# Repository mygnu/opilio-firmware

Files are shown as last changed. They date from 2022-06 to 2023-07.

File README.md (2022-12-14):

# opilio-firmware

Firmware for STM32F103C8 based custom board for PC water-cooling project.

Counterparts: 
- Linux TUI app can be found [here](https://github.com/mygnu/opilio)
- PCB Files [here](https://github.com/mygnu/opilio-pcb)

## Flashing an opilio board
- install rust from [rustup](https://rustup.rs)
- `cargo install probe-run cargo-flash flip-link`
- `git clone https://github.com/mygnu/opilio`
- `git clone https://github.com/mygnu/opilio-firmware`
- `cd opilio-firmware && cargo flash --chip STM32F103C8 --release`

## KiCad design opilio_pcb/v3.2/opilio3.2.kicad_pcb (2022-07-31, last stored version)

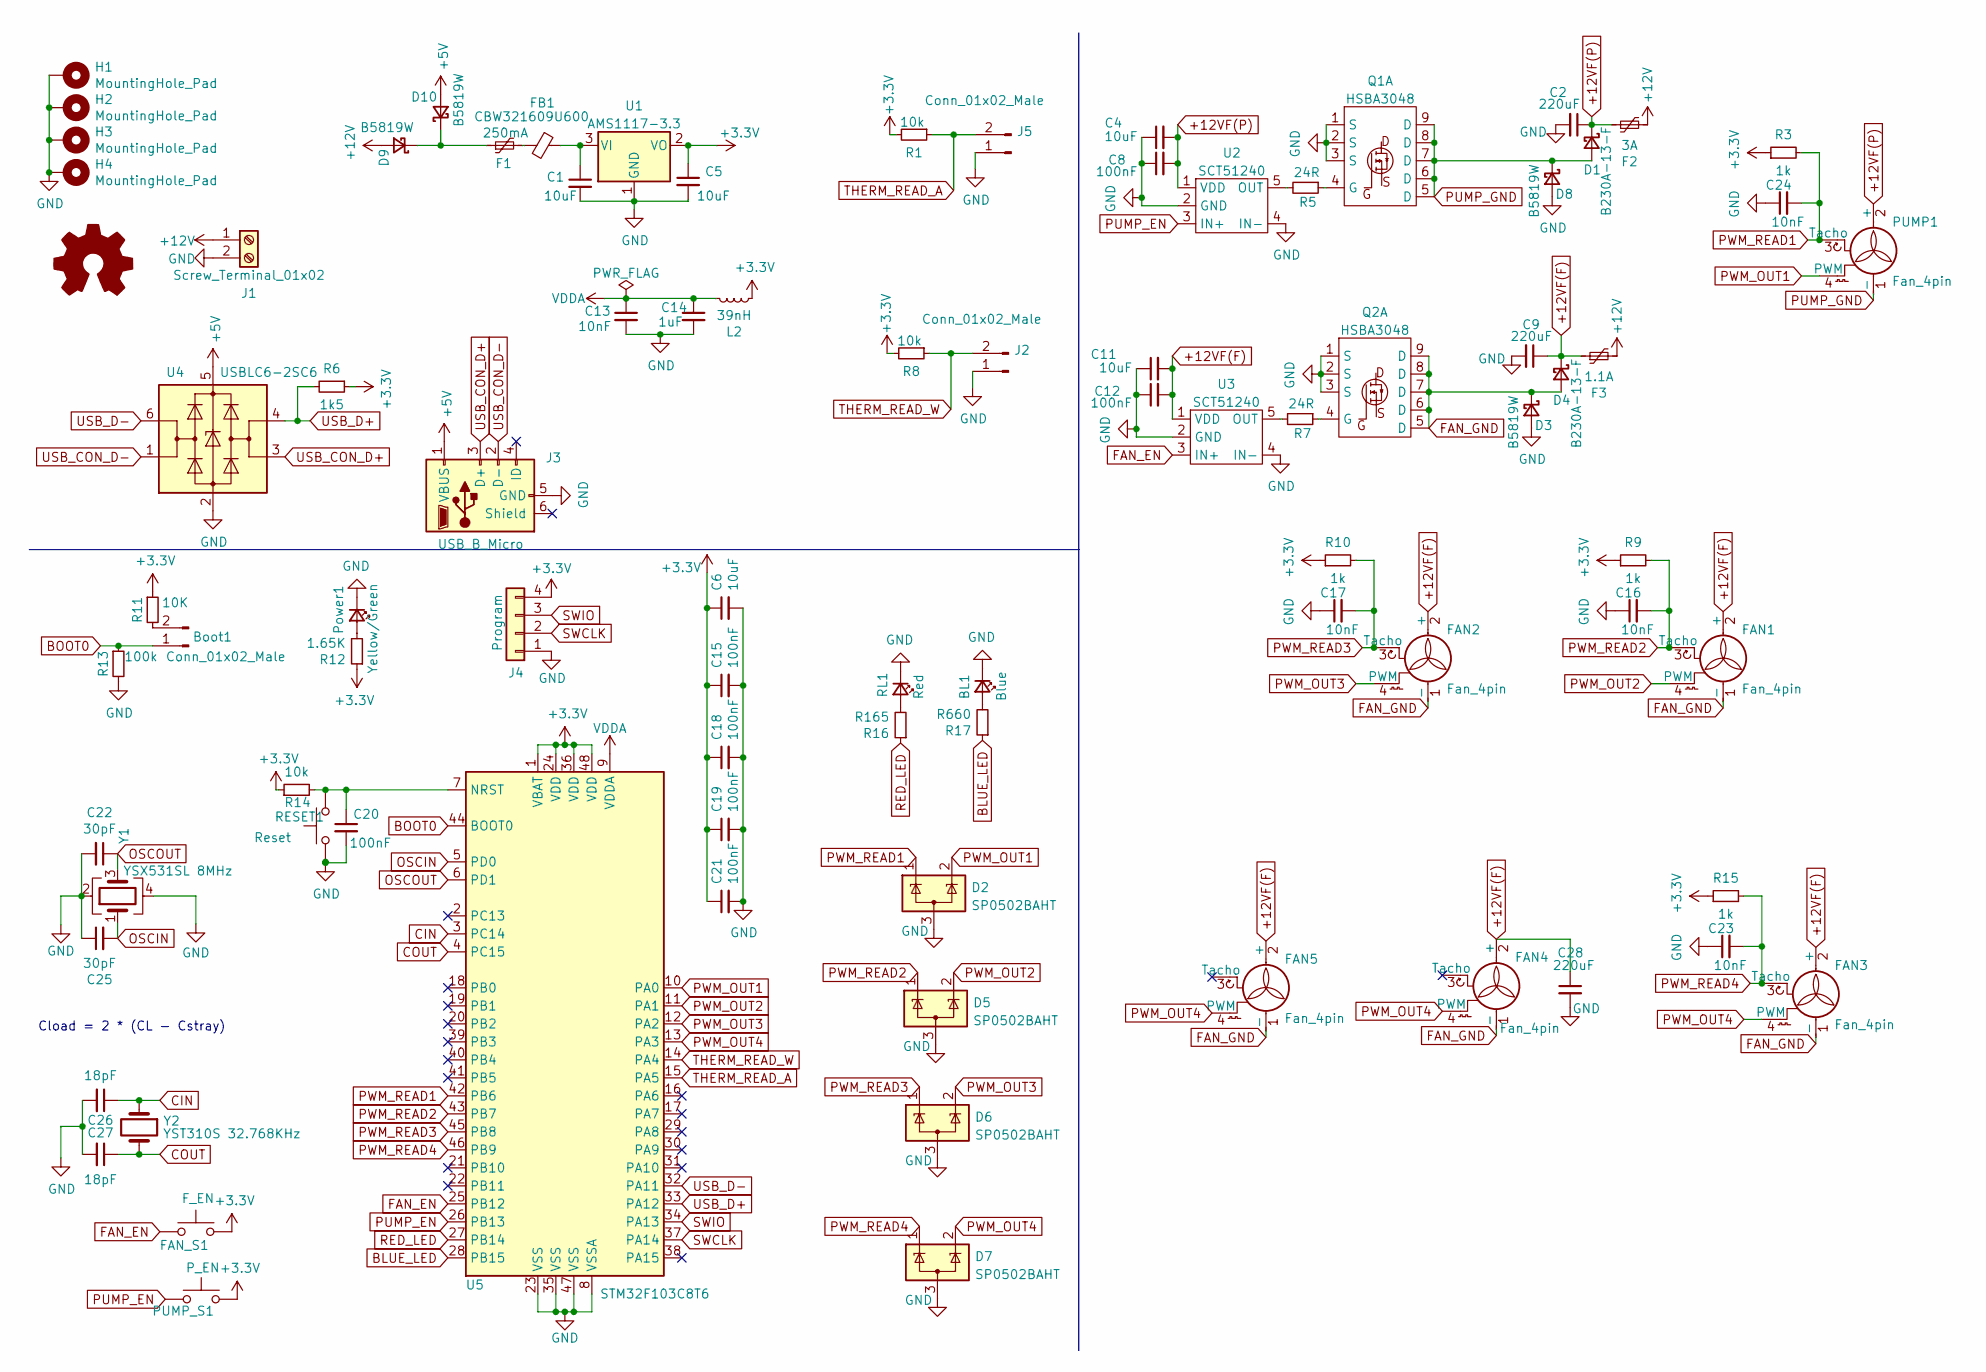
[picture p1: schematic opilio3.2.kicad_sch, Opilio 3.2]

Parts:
BL1: Blue; LED_0603_1608Metric_Pad1.05x0.95mm_HandSolder
Boot1: Conn_01x02_Male; PinHeader_1x02_P2.54mm_Vertical
C1, C4, C5, C6, C11: 10uF; C_0603_1608Metric_Pad1.08x0.95mm_HandSolder
C2, C9, C28: 220uF; CP_Elec_6.3x7.7
C8, C12, C15, C18, C19, C20, C21: 100nF; C_0603_1608Metric_Pad1.08x0.95mm_HandSolder
C13, C16, C17, C23, C24: 10nF; C_0603_1608Metric_Pad1.08x0.95mm_HandSolder
C14: 1uF; C_0603_1608Metric_Pad1.08x0.95mm_HandSolder
C22, C25: 30pF; C_0603_1608Metric_Pad1.08x0.95mm_HandSolder
C26, C27: 18pF; C_0603_1608Metric_Pad1.08x0.95mm_HandSolder
D1, D4: B230A-13-F; D_SMA
D2, D5, D6, D7: SP0502BAHT; SOT-23
D3, D8, D9, D10: B5819W; D_SOD-123
F1: 250mA; Fuse_1206_3216Metric_Pad1.42x1.75mm_HandSolder
F2: 3A; Fuse_1812_4532Metric_Pad1.30x3.40mm_HandSolder
F3: 1.1A; Fuse_1206_3216Metric_Pad1.42x1.75mm_HandSolder
FAN1, FAN2, FAN3, FAN4, FAN5: Fan_4pin; FanPinHeader_1x04_P2.54mm_Vertical_no_hole
FAN_S1: F_EN; SW-SMD_L6.0-W3.3-LS8.0
FB1: CBW321609U600; C_1206_3216Metric_Pad1.33x1.80mm_HandSolder
H1, H2, H3, H4: MountingHole_Pad; MountingHole_3mm_Pad_Via
J1: Screw_Terminal_01x02; TerminalBlock_bornier-2_P5.08mm
J2, J5: Conn_01x02_Male; PinHeader_1x02_P2.54mm_Vertical
J3: USB_B_Micro; USB_Micro-B_Wuerth_629105150521_narrow_holes
J4: Program; PinHeader_1x04_P2.54mm_Vertical
L2: 39nH; L_0805_2012Metric_Pad1.05x1.20mm_HandSolder
LOGO1: Logo_Open_Hardware_Small; OSHW-Logo2_9.8x8mm_SilkScreen
PUMP1: Fan_4pin; FanPinHeader_1x04_P2.54mm_Vertical_no_hole
PUMP_S1: P_EN; SW-SMD_L6.0-W3.3-LS8.0
Power1: Yellow/Green; LED_0603_1608Metric_Pad1.05x0.95mm_HandSolder
Q1, Q2: HSBA3048; PDFN-8_L5.6-W5.2-P1.27-LS6.1-BL
R1, R8, R14: 10k; R_0603_1608Metric_Pad0.98x0.95mm_HandSolder
R3, R9, R10, R15: 1k; R_0603_1608Metric_Pad0.98x0.95mm_HandSolder
R5, R7: 24R; R_0603_1608Metric_Pad0.98x0.95mm_HandSolder
R6: 1k5; R_0603_1608Metric_Pad0.98x0.95mm_HandSolder
R11: 10K; R_0603_1608Metric_Pad0.98x0.95mm_HandSolder
R12: 1.65K; R_0603_1608Metric_Pad0.98x0.95mm_HandSolder
R13: 100k; R_0603_1608Metric_Pad0.98x0.95mm_HandSolder
R16: R165; R_0603_1608Metric_Pad0.98x0.95mm_HandSolder
R17: R660; R_0603_1608Metric_Pad0.98x0.95mm_HandSolder
RESET1: Reset; SW-SMD_L6.0-W3.3-LS8.0
RL1: Red; LED_0603_1608Metric_Pad1.05x0.95mm_HandSolder
U1: AMS1117-3.3; SOT-223-3_TabPin2
U2, U3: SCT51240; SOT-23-5_HandSoldering
U4: USBLC6-2SC6; SOT-23-6
U5: STM32F103C8T6; LQFP-48_7x7mm_P0.5mm
Y1: YSX531SL 8MHz; Crystal_SMD_3225-4Pin_3.2x2.5mm
Y2: YST310S 32.768KHz; Crystal_SMD_3215-2Pin_3.2x1.5mm

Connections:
+3.3V: C5.1, C6.1, C15.1, C18.1, C19.1, C21.1, FAN_S1.2, J4.4, L2.1, PUMP_S1.2, R1.2, R3.1, R6.1, R8.2, R9.1, R10.1, R11.1, R12.1, R14.1, R15.1, U1.2 (VO), U5.1 (VBAT), U5.24 (VDD), U5.36 (VDD), U5.48 (VDD)
+5V: D10.2 (A), J3.1 (VBUS), U4.5 (VBUS)
+12V: D9.2 (A), F2.2, F3.2, J1.1
+12VF(F): C9.1, C11.2, C12.2, C28.1, D4.1 (K), F3.1, FAN1.2 (+), FAN2.2 (+), FAN3.2 (+), FAN4.2 (+), FAN5.2 (+), U3.1 (VDD)
+12VF(P): C2.1, C4.2, C8.2, D1.1 (K), F2.1, PUMP1.2 (+), U2.1 (VDD)
BLUE_LED: R17.1, U5.28 (PB15)
BOOT0: Boot1.1, R13.1, U5.44 (BOOT0)
CIN: C26.1, U5.3 (PC14), Y2.1
COUT: C27.1, U5.4 (PC15), Y2.2
FAN_EN: FAN_S1.1, U3.3 (IN+), U5.25 (PB12)
FAN_GND: D3.1 (K), D4.2 (A), FAN1.1 (-), FAN2.1 (-), FAN3.1 (-), FAN4.1 (-), FAN5.1 (-), Q2.5 (D), Q2.6 (D), Q2.7 (D), Q2.8 (D), Q2.9 (D)
GND: BL1.1 (K), C1.2, C2.2, C4.1, C5.2, C6.2, C8.1, C9.2, C11.1, C12.1, C13.2, C14.2, C15.2, C16.1, C17.1, C18.2, C19.2, C20.2, C21.2, C22.2, C23.1, C24.1, C25.1, C26.2, C27.2, C28.2, D2.3 (A), D3.2 (A), D5.3 (A), D6.3 (A), D7.3 (A), D8.2 (A), H1.1, H2.1, H3.1, H4.1, J1.2, J2.1, J3.5 (GND), J4.1, J5.1, Power1.1 (K), Q1.1 (S), Q1.2 (S), Q1.3 (S), Q2.1 (S), Q2.2 (S), Q2.3 (S), R13.2, RESET1.1, RL1.1 (K), U1.1 (GND), U2.2 (GND), U2.4 (IN-), U3.2 (GND), U3.4 (IN-), U4.2 (GND), U5.8 (VSSA), U5.23 (VSS), U5.35 (VSS), U5.47 (VSS), Y1.2, Y1.4
unnamed: BL1.2 (A), R17.2
unnamed: Boot1.2, R11.2
unnamed: C1.1, FB1.1, U1.3 (VI)
unnamed: C20.1, R14.2, RESET1.2, U5.7 (NRST)
unnamed: D9.1 (K), D10.1 (K), F1.1
unnamed: F1.2, FB1.2
unnamed: Power1.2 (A), R12.2
unnamed: Q1.4 (G), R5.1
unnamed: Q2.4 (G), R7.1
unnamed: R5.2, U2.5 (OUT)
unnamed: R7.2, U3.5 (OUT)
unnamed: R16.2, RL1.2 (A)
OSCIN: C25.2, U5.5 (PD0), Y1.1
OSCOUT: C22.1, U5.6 (PD1), Y1.3
PUMP_EN: PUMP_S1.1, U2.3 (IN+), U5.26 (PB13)
PUMP_GND: D1.2 (A), D8.1 (K), PUMP1.1 (-), Q1.5 (D), Q1.6 (D), Q1.7 (D), Q1.8 (D), Q1.9 (D)
PWM_OUT1: D2.2 (K), PUMP1.4 (PWM), U5.10 (PA0)
PWM_OUT2: D5.2 (K), FAN1.4 (PWM), U5.11 (PA1)
PWM_OUT3: D6.2 (K), FAN2.4 (PWM), U5.12 (PA2)
PWM_OUT4: D7.2 (K), FAN3.4 (PWM), FAN4.4 (PWM), FAN5.4 (PWM), U5.13 (PA3)
PWM_READ1: C24.2, D2.1 (K), PUMP1.3 (Tacho), R3.2, U5.42 (PB6)
PWM_READ2: C16.2, D5.1 (K), FAN1.3 (Tacho), R9.2, U5.43 (PB7)
PWM_READ3: C17.2, D6.1 (K), FAN2.3 (Tacho), R10.2, U5.45 (PB8)
PWM_READ4: C23.2, D7.1 (K), FAN3.3 (Tacho), R15.2, U5.46 (PB9)
RED_LED: R16.1, U5.27 (PB14)
SWCLK: J4.2, U5.37 (PA14)
SWIO: J4.3, U5.34 (PA13)
THERM_READ_A: J5.2, R1.1, U5.15 (PA5)
THERM_READ_W: J2.2, R8.1, U5.14 (PA4)
USB_CON_D+: J3.3 (D+), U4.3 (I/O2)
USB_CON_D-: J3.2 (D-), U4.1 (I/O1)
USB_D+: R6.2, U4.4 (I/O2), U5.33 (PA12)
USB_D-: U4.6 (I/O1), U5.32 (PA11)
VDDA: C13.1, C14.1, L2.2, U5.9 (VDDA)

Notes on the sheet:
Cload = 2 * (CL - Cstray)

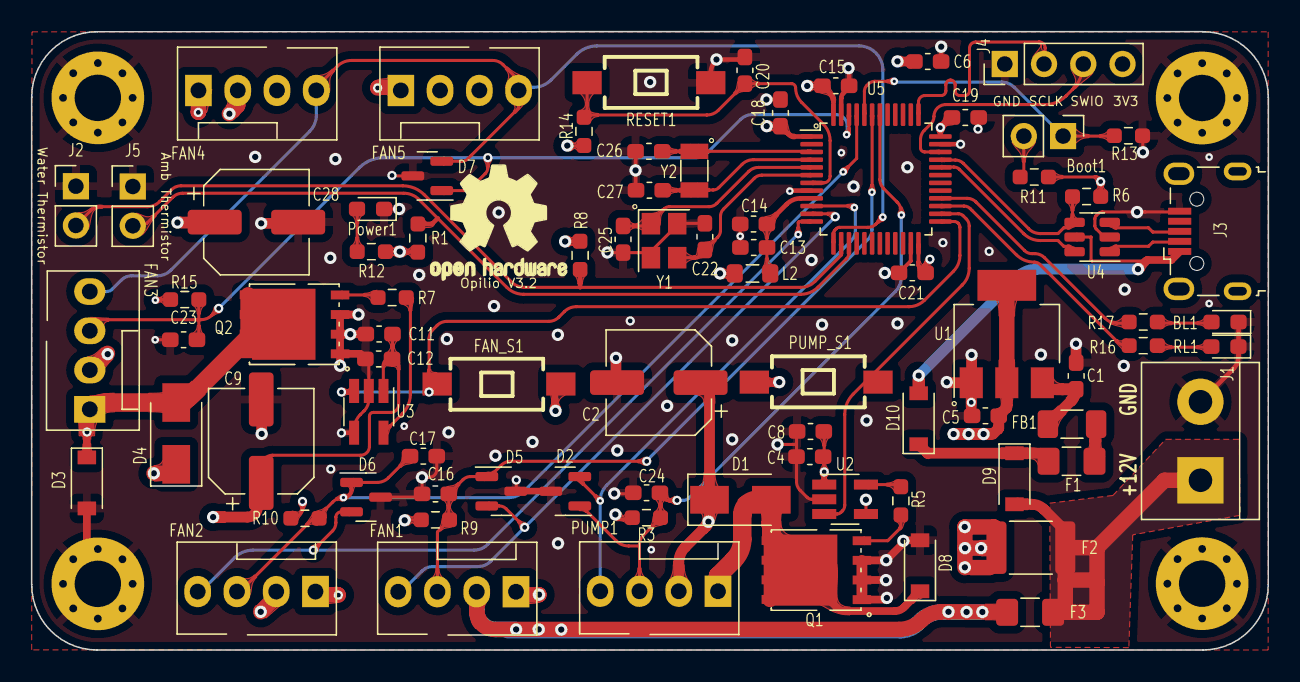
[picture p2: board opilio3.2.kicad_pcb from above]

Board: 4 copper layers, 80.0 x 40.0 mm, 87 parts (0 on the bottom side), 46 nets.

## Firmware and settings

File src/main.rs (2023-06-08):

#![no_main]
#![no_std]

#[rtic::app(device = stm32f1xx_hal::pac, dispatchers = [RTC], peripherals = true)]
mod app {

    use cortex_m::asm::delay;
    use defmt::{debug, trace};
    use opilio_firmware::{
        controller::{Controller, RgbLed, Temps, TICK_PERIOD},
        serial_handler::UsbHandler,
        tacho::TachoReader,
        FlashOps, PwmTimer2,
    };
    use opilio_lib::{Config, Id, PID, VID};
    use stm32f1xx_hal::{
        adc::Adc,
        flash::{FlashExt, Parts},
        pac::TIM4,
        prelude::*,
        timer::Tim2NoRemap,
        usb::{Peripheral, UsbBus, UsbBusType},
    };
    use systick_monotonic::{ExtU64, Systick};
    use usb_device::prelude::*;

    const VERSION: &str = "1.2.0";

    use super::timer_setup::timer4_input_setup;

    #[monotonic(binds = SysTick, default = true)]
    type MyMono = Systick<100>; // 100 Hz / 10 ms granularity

    #[shared]
    struct Shared {
        config: Config,
        controller: Controller,
        tacho: TachoReader,
        tick: u64,
    }

    #[local]
    struct Local {
        usb_handler: UsbHandler<UsbBusType>,
        flash: Parts,
    }

    #[init]
    fn init(cx: init::Context) -> (Shared, Local, init::Monotonics) {
        static mut USB_BUS: Option<
            usb_device::bus::UsbBusAllocator<UsbBusType>,
        > = None;

        let device = cx.device;
        let mut flash = device.FLASH.constrain();
        let rcc = device.RCC.constrain();

        let clocks = rcc
            .cfgr
            .adcclk(8.MHz())
            .use_hse(8.MHz())
            .sysclk(48.MHz())
            .pclk1(24.MHz())
            .freeze(&mut flash.acr);

        assert!(clocks.usbclk_valid());

        let adc1 = Adc::adc1(device.ADC1, clocks);

        let mut gpioa = device.GPIOA.split();
        let mut afio = device.AFIO.constrain();
        let mut gpiob = device.GPIOB.split();

        // BluePill board has a pull-up resistor on the D+ line.
        // Pull the D+ pin down to send a RESET condition to the USB bus.
        // This forced reset is needed only for development, without it host
        // will not reset your device when you upload new firmware.
        let mut usb_dp = gpioa.pa12.into_push_pull_output(&mut gpioa.crh);
        usb_dp.set_low();
        delay(clocks.sysclk().raw() / 10);

        let usb_dm = gpioa.pa11;
        let usb_dp = usb_dp.into_floating_input(&mut gpioa.crh);

        let usb = Peripheral {
            usb: device.USB,
            pin_dm: usb_dm,
            pin_dp: usb_dp,
        };

        unsafe {
            USB_BUS.replace(UsbBus::new(usb));
        }

        let serial =
            usbd_serial::SerialPort::new(unsafe { USB_BUS.as_ref().unwrap() });

        let usb_dev = UsbDeviceBuilder::new(
            unsafe { USB_BUS.as_ref().unwrap() },
            UsbVidPid(VID, PID),
        )
        .manufacturer("Open Hardware")
        .product("Opilio - PC Fan/Pump Controller")
        .serial_number(VERSION)
        .device_class(usbd_serial::USB_CLASS_CDC)
        .build();

        let usb_handler = UsbHandler::new(usb_dev, serial);

        // Initialize the monotonic (SysTick rate is 48 MHz)
        let mono = Systick::new(cx.core.SYST, 48_000_000);

        // Configure pa4 as an analog input
        let ambient_thermistor = gpioa.pa4.into_analog(&mut gpioa.crl);
        let coolant_thermistor = gpioa.pa5.into_analog(&mut gpioa.crl);
        let coolant_out_thermistor = gpioa.pa6.into_analog(&mut gpioa.crl);

        let pins_a0_a3 = (
            gpioa.pa0.into_alternate_push_pull(&mut gpioa.crl),
            gpioa.pa1.into_alternate_push_pull(&mut gpioa.crl),
            gpioa.pa2.into_alternate_push_pull(&mut gpioa.crl),
            gpioa.pa3.into_alternate_push_pull(&mut gpioa.crl),
        );
        let pwm_timer2: PwmTimer2 = device.TIM2.pwm_hz::<Tim2NoRemap, _, _>(
            pins_a0_a3,
            &mut afio.mapr,
            24.kHz(),
            &clocks,
        );

        let buzzer = gpiob.pb11.into_push_pull_output(&mut gpiob.crh);
        let pump_power = gpiob.pb12.into_push_pull_output(&mut gpiob.crh);
        let fan_power = gpiob.pb13.into_push_pull_output(&mut gpiob.crh);
        let red_led = gpiob.pb14.into_push_pull_output(&mut gpiob.crh);
        let green_led = gpioa.pa8.into_push_pull_output(&mut gpioa.crh);
        let blue_led = gpiob.pb15.into_push_pull_output(&mut gpiob.crh);
        let mut led = RgbLed::new(red_led, green_led, blue_led);
        led.exclusive_on(opilio_firmware::controller::Led::GREEN);

        let config = if let Ok(config) = Config::from_flash(&mut flash) {
            if config.is_valid() {
                defmt::debug!("Config from disk: {:?}", config);
                config
            } else {
                defmt::error!("Invalid {:?}", config);
                Config::default()
            }
        } else {
            let config = Config::default();
            defmt::error!("Failed to create, using Default {}", config);
            config
        };

        let temps = Temps::new(
            adc1,
            ambient_thermistor,
            coolant_thermistor,
            coolant_out_thermistor,
        );

        let controller = Controller::new(
            pwm_timer2, pump_power, fan_power, buzzer, temps, led,
        );

        timer4_input_setup(gpiob.pb6, gpiob.pb7, gpiob.pb8, gpiob.pb9);

        let tacho = TachoReader::default();

        periodic::spawn().ok();

        (
            Shared {
                config,
                controller,
                tacho,
                tick: 0,
            },
            Local { usb_handler, flash },
            init::Monotonics(mono),
        )
    }

    #[task(shared = [controller, config, tacho, tick])]
    fn periodic(cx: periodic::Context) {
        trace!("periodic");

        (cx.shared.controller, cx.shared.config, cx.shared.tick).lock(
            |ctl, config, tick| {
                if *tick > config.general.sleep_after as u64 * 1000 {
                    ctl.adjust_pwm(config, true);
                } else {
                    ctl.adjust_pwm(config, false);
                    *tick = tick.saturating_add(TICK_PERIOD);
                }
            },
        );

        periodic::spawn_after(TICK_PERIOD.millis()).ok();
    }

    // #[task(binds = USB_HP_CAN_TX, shared = [])]
    // fn usb_tx(_cx: usb_tx::Context) {
    //     debug!("usb tx");
    // }

    #[idle]
    fn idle(_cx: idle::Context) -> ! {
        loop {
            // defmt::info!("idle");
            rtic::export::nop();
        }
    }

    /// timer4 interrupt handler
    /// triggers every time a channel is on the rising edge
    /// updates the tacho value to be
    #[task(binds = TIM4, shared = [tacho])]
    fn tim4(mut cx: tim4::Context) {
        let tim = unsafe { &(*TIM4::ptr()) };

        cx.shared.tacho.lock(|t| {
            let status_register = tim.sr.read();
            if status_register.cc1if().bit_is_set() {
                let current = tim.ccr1().read().bits() as u16;
                t.update(Id::P1, current);
                tim.sr.write(|w| w.cc1if().clear_bit());
            } else if status_register.cc2if().bit_is_set() {
                let current = tim.ccr2().read().bits() as u16;
                t.update(Id::F1, current);

                tim.sr.write(|w| w.cc2if().clear_bit());
            } else if status_register.cc3if().bit_is_set() {
                let current = tim.ccr3().read().bits() as u16;
                t.update(Id::F2, current);

                tim.sr.write(|w| w.cc3if().clear_bit());
            } else if status_register.cc4if().bit_is_set() {
                let current = tim.ccr4().read().bits() as u16;
                t.update(Id::F3, current);
                tim.sr.write(|w| w.cc4if().clear_bit());
            }
        });
        tim.sr.write(|w| w.uif().clear_bit());
    }

    /// usb_rx0 interrupt handler
    /// triggers every time there is incoming data on usb serial bus
    #[task(binds = USB_LP_CAN_RX0, local = [usb_handler, flash], shared = [ config,  tick, controller, tacho])]
    fn usb_rx0(cx: usb_rx0::Context) {
        debug!("usb rx");
        let usb_handler = cx.local.usb_handler;
        let mut config = cx.shared.config;
        let flash = cx.local.flash;
        let mut tick = cx.shared.tick;
        let mut controller = cx.shared.controller;
        let mut tacho = cx.shared.tacho;

        // reset tick on usb communication
        tick.lock(|c| {
            *c = 0;
        });

        (&mut config, &mut controller, &mut tacho).lock(
            |config, controller, tacho| {
                usb_handler.poll(config, flash, controller, tacho);
            },
        );
    }
}

mod timer_setup {
    use stm32f1xx_hal::{
        gpio::{Floating, Input, PB6, PB7, PB8, PB9},
        pac::{Interrupt, RCC, TIM4},
        rcc::{Enable, Reset},
    };

    /// since main clock is 48Mhz,
    /// 480 prescaler gives us a nice 10 microsecond tick
    /// good enough to measure fan rpm values
    pub const PRESCALER: u16 = 480;

    /// setup timer (fake consumption of pins so we don't accidentally use them
    /// for other purposes)
    pub fn timer4_input_setup(
        _pb6: PB6<Input<Floating>>,
        _pb7: PB7<Input<Floating>>,
        _pb8: PB8<Input<Floating>>,
        _pb9: PB9<Input<Floating>>,
    ) {
        let tim = unsafe { &(*TIM4::ptr()) };

        unsafe {
            //NOTE(unsafe) this reference will only be used for atomic writes
            // with no side effects
            let rcc = &(*RCC::ptr());
            // Enable and reset the timer peripheral
            TIM4::enable(rcc);
            TIM4::reset(rcc);
        }

        // PB6, PB7, PB8, PB9
        // Disable capture on all 4 channels during setting
        // (for Channel X bit is CCXE)
        tim.ccer.modify(|_, w| {
            w.cc1e()
                .clear_bit()
                .cc2e()
                .clear_bit()
                .cc3e()
                .clear_bit()
                .cc4e()
                .clear_bit()
                .cc1p()
                .set_bit()
                .cc2p()
                .set_bit()
                .cc3p()
                .set_bit()
                .cc4p()
                .set_bit()
        });

        // configure capture/compare mode resistors and map Timer Input
        // registers
        tim.ccmr1_input().modify(|_, w| w.cc1s().ti1().cc2s().ti2());
        tim.ccmr2_input().modify(|_, w| w.cc3s().ti3().cc4s().ti4());

        // configure DMA enable interrupt register for all 4 channels
        tim.dier.write(|w| {
            w.cc1ie()
                .enabled()
                .cc2ie()
                .enabled()
                .cc3ie()
                .enabled()
                .cc4ie()
                .enabled()
        });

        // Configure slave mode control register
        // Selects the trigger input to be used to synchronize the counter
        // 101: Filtered Timer Input 1 (TI1FP1)
        // ---------------------------------------
        // Slave Mode Selection :
        // Trigger Mode - The counter starts at a rising edge of the trigger
        // TRGI (but it is not reset). Only the start of the counter is
        // controlled.
        tim.smcr.modify(|_, w| w.ts().ti1fp1().sms().trigger_mode());

        // set auto reload register and prescaler
        tim.arr.write(|w| w.arr().bits(u16::MAX));
        tim.psc.write(|w| w.psc().bits(PRESCALER));

        // enable capture/compare
        tim.ccer.modify(|_, w| {
            w.cc1e()
                .set_bit()
                .cc2e()
                .set_bit()
                .cc3e()
                .set_bit()
                .cc4e()
                .set_bit()
        });

        // enable timer counter
        tim.cr1.modify(|_, w| w.cen().set_bit());

        // setup timer interrupt
        unsafe { cortex_m::peripheral::NVIC::unmask(Interrupt::TIM4) };
    }
}

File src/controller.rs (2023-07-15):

use cortex_m::prelude::_embedded_hal_adc_OneShot;
use defmt::{debug, info, trace};
use micromath::F32Ext;
use opilio_lib::{
    error::Error, get_smart_duty, Config, Id, Result, SwitchMode,
    TempratureInput,
};
use stm32f1xx_hal::{
    adc::Adc,
    gpio::{
        gpioa::PA4, Analog, Output, PushPull, PA5, PA6, PA8, PB11, PB12, PB13,
        PB14, PB15,
    },
    pac::ADC1,
    timer::Channel,
};

use crate::PwmTimer2;

/// 10k resistor measured resistance in Ohms
const R_10K: f32 = 10000.0;
/// voltage to the V-REF
const V_SUPPLY: f32 = 3.2925;
/// B-coefficient of the thermistor (guessed)
const B_PARAM: f32 = 3700.0;

/// 0*C in kelvin
const ZERO_K_IN_C: f32 = 273.15;

// voltage supply / ADC resolution
const ADC_RATIO: f32 = V_SUPPLY / 4096.0;

// milliseconds
pub const TICK_PERIOD: u64 = 450_u64;

pub const DEFAULT_TEMP: f32 = 22.0;

trait ChannelMap {
    fn channel(&self) -> Channel;
}

impl ChannelMap for Id {
    fn channel(&self) -> Channel {
        use Channel::*;
        use Id::*;

        match self {
            P1 => C1,
            F1 => C2,
            F2 => C3,
            F3 => C4,
        }
    }
}

pub enum Led {
    RED,
    GREEN,
    BLUE,
    ALL,
}

pub struct RgbLed {
    pub use_led: bool,
    red_led: PB14<Output<PushPull>>,
    green_led: PA8<Output<PushPull>>,
    blue_led: PB15<Output<PushPull>>,
}

impl RgbLed {
    #[inline]
    pub fn new(
        red_led: PB14<Output<PushPull>>,
        green_led: PA8<Output<PushPull>>,
        blue_led: PB15<Output<PushPull>>,
    ) -> Self {
        Self {
            use_led: true,
            red_led,
            green_led,
            blue_led,
        }
    }

    #[inline]
    pub fn exclusive_on(&mut self, led: Led) {
        if self.use_led {
            match led {
                Led::RED => {
                    self.red_led.set_low();
                    self.green_led.set_high();
                    self.blue_led.set_high();
                }
                Led::GREEN => {
                    self.red_led.set_high();
                    self.green_led.set_low();
                    self.blue_led.set_high();
                }
                Led::BLUE => {
                    self.red_led.set_high();
                    self.green_led.set_high();
                    self.blue_led.set_low();
                }
                Led::ALL => {
                    self.red_led.set_low();
                    self.green_led.set_low();
                    self.blue_led.set_low();
                }
            }
        } else {
            self.off(led)
        }
    }

    pub fn toggle(&mut self, led: Led) {
        if self.use_led {
            match led {
                Led::RED => {
                    self.red_led.toggle();
                }
                Led::GREEN => {
                    self.green_led.toggle();
                }
                Led::BLUE => {
                    self.blue_led.toggle();
                }
                Led::ALL => {
                    self.red_led.toggle();
                    self.green_led.toggle();
                    self.blue_led.toggle();
                }
            }
        } else {
            self.off(led)
        }
    }

    #[inline]
    pub fn off(&mut self, led: Led) {
        match led {
            Led::RED => {
                self.red_led.set_high();
            }
            Led::GREEN => {
                self.green_led.set_high();
            }
            Led::BLUE => {
                self.blue_led.set_high();
            }
            Led::ALL => {
                self.red_led.set_high();
                self.green_led.set_high();
                self.blue_led.set_high();
            }
        }
    }
}

pub struct Temps {
    adc: Adc<ADC1>,
    ambient_temp: f32,
    ambient_thermistor: PA4<Analog>,
    coolant_temp: f32,
    coolant_thermistor: PA5<Analog>,
    coolant_out_temp: f32,
    coolant_out_thermistor: PA6<Analog>,
}

pub enum Thermistor {
    Coolant,
    CoolantOut,
    Ambient,
}

impl Temps {
    pub fn new(
        adc: Adc<ADC1>,
        ambient_thermistor: PA4<Analog>,
        coolant_thermistor: PA5<Analog>,
        coolant_out_thermistor: PA6<Analog>,
    ) -> Self {
        Self {
            adc,
            ambient_temp: DEFAULT_TEMP,
            ambient_thermistor,
            coolant_temp: DEFAULT_TEMP,
            coolant_thermistor,
            coolant_out_temp: DEFAULT_TEMP,
            coolant_out_thermistor,
        }
    }

    pub fn read(&mut self, thermistor: Thermistor) -> Result<()> {
        match thermistor {
            Thermistor::Coolant => {
                let adc_reading = self
                    .adc
                    .read(&mut self.coolant_thermistor)
                    .map_err(|_| Error::TempRead)?;

                let new_temp = adc_reading_to_temp(adc_reading);
                self.coolant_temp = (self.coolant_temp + new_temp) / 2.0;
                if new_temp < -20.0 {
                    return Err(Error::TempRead);
                }
            }
            Thermistor::CoolantOut => {
                let adc_reading = self
                    .adc
                    .read(&mut self.coolant_out_thermistor)
                    .map_err(|_| Error::TempRead)?;

                let new_temp = adc_reading_to_temp(adc_reading);
                self.coolant_out_temp =
                    (self.coolant_out_temp + new_temp) / 2.0;
            }
            Thermistor::Ambient => {
                let adc_reading = self
                    .adc
                    .read(&mut self.ambient_thermistor)
                    .map_err(|_| Error::TempRead)?;

                let new_temp = adc_reading_to_temp(adc_reading);
                self.ambient_temp = (self.ambient_temp + new_temp) / 2.0;
            }
        }
        Ok(())
    }
}

/// controller for most of the output of opilio
/// Responsible for
/// - Reading thermistor and converting it to temperature in C
/// - Enable/Disable fan and pump MOSFETs (via MOSFET drivers)
/// - Controls Red an Blue single leds
/// - Controls PWM signal for Fans and pumps
pub struct Controller {
    temps: Temps,
    buzzer_pin: PB11<Output<PushPull>>,
    fan_power: PB13<Output<PushPull>>,
    led: RgbLed,
    max_duty_value: u16,
    pump_power: PB12<Output<PushPull>>,
    pwm_timer: PwmTimer2,
    use_buzzer: bool,
}
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

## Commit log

2022-06-28 Add KiCad project files, and update readme (#4)
    * add renders and KiCad project files
    [opilio3.kicad_pcb, opilio3.kicad_sch]
2022-07-02 improve usb serial communication (#5)
    * improved documentation
    * basic data fetch and charts
    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
2022-07-03 update device name
2022-07-16 Board updated to v3.1 (#7)
    * refactor to updated shared lib
    * stabalize temp reading by averaging
    * stabalize temp reading by averaging
    * move schematice tiny bit
    * add power flag
    * common
    * save standby
    * move duty calculation to config, prep for fan curve
    * update pcb
    * set led high if thermister value is too low
    * deal with entire config
    * add pcb v3.1
    * moved opilio 3.1
    * almost ready for v3.1
    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
    [opilio3.1.kicad_pcb, opilio3.1.kicad_sch, opilio3.kicad_pcb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]
2022-07-31 Pcb update to v3.2 (#9)
    * v3.2
    * cleanup
    [opilio3.2.kicad_pcb, opilio3.2.kicad_sch]
2022-07-31 pcb update
    [opilio3.2.kicad_pcb]
2022-12-11 improve ui (#8)
    * move renders out
    * update render
    * refactor
    * refactor usb serial
    * split and set each setting
    * if liquid temp is cooler than the ambient, turn off fans
    * if liquid temp is cooler than the ambient, turn off fans
    * butter handeling of stuff
    * pcb render
    * add bom
    * cargo update
    * smaller mosfets
    * v4 almost ready
    * ordered
    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
    [opilio3.1.kicad_pcb, opilio3.1.kicad_sch, opilio3.2.kicad_pcb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]
2023-06-08 allow led and primary tepm input settings
